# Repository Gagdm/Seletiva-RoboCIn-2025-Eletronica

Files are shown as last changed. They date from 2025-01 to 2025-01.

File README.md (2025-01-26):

# Conversor DC-DC com SIC437A

Este projeto implementa um conversor buck baseado no controlador SIC437A da Vishay.

## Objetivo
Desenvolver um regulador DC-DC, utilizando a ferramenta Altium Designer, que receba uma tensão de entrada entre 7,4V e 25,2V e forneça uma saída constante de 5V com corrente mínima de 5A. Além disso, é necessário atentar não apenas para a eficiência do circuito (mínima de 90%), mas também para o valor e as dimensões dos componentes.

---

Echematic

---

### 🟡
- Esta seção é responsável por receber a alimentação do circuito, filtrá-la e garantir uma entrada limpa e estável para o regulador de tensão.

#### Componentes
- JIN? : Um conector para a entrada de alimentação.
- CINB? (150uF): Capacitor de desacoplamento o qual remove ruídos transitórios, como picos de tensão causados pela fonte ou pelo chaveamento do regulador.
- CIND? (0,1uF): Também um capacitor de desacoplamento, trabalhando em conjunto com CINB? para aumentar a eficiência do filtro, abordando diferentes faixas de frequências indesejadas.
> No geral, Esses capacitores garantem que a tensão entregue ao regulador seja o mais estável possível, evitando ruídos que possam interferir no funcionamento do circuito.

---

### 🔴
- Formam um divisor de tensão que define a tensão de saída (VOUT) do regulador e alimentam o pino de feedback (FB), permitindo ao controlador ajustar o ciclo de trabalho (duty cycle) para manter a saída estável.

#### Componentes
- Os resistores RFB1 (73,2kΩ) e RFB2 (10kΩ) dividem a tensão de saída (VOUT) para gerar um sinal proporcional que é enviado ao pino FB do regulador. Dessa forma, ajustam a tensão de saída do regulador e garantem que o feedback forneça um sinal preciso ao controlador.

$$
RFB1 = \frac{FRB2 (V_{out} - V_{FB})}{V_{FB}}
$$

Temos, Vout = 5V, RFB1 = 10kΩ e Vfb = 0,6V (RFB1 e Vfb são definidos no datasheet do SIC437). Portanto,

$$
RFB1 = \frac{10.10^{3} (5 - 0,6)}{0,6} \simeq 73.333Ω \simeq 73,2kΩ
$$

- COUTD (0,1uF): Reduz ruídos de alta frequência na saída do regulador, ajudando a garantir uma tensão limpa e estável.
> Resumidamente, Permitem que o regulador monitore e ajuste a tensão de saída para mantê-la estável, além de determinam a tensão de saída por meio do divisor resistivo.

---

### 🟢
- Divisor de Tensão, esses resistores formam um divisor de tensão entre VIN (tensão de entrada) e o pino EN do regulador. O objetivo é garantir que o regulador seja habilitado somente quando a tensão de entrada atinge um valor mínimo seguro, prevenindo operação em condições inadequadas.

#### Componentes
- RenH (562kΩ)
- RenL (309kΩ)
> De forma geral, Funcionam como um divisor de tensão e proteção contra subvoltagem.

---

### 🔵 
- Esta parte auxilia o circuito de chaveamento do regulador, especialmente para operar o MOSFET superior em um regulador buck.

#### Componentes
- CBOOT? (0,1µF): Capacitor de bootstrap,fornecendo a energia necessária para acionar o MOSFET superior (high-side) durante o chaveamento, além de ser carregado toda vez que o MOSFET inferior (low-side) está conduzindo.
- RBOOT? (2Ω): Resistor em série com o capacitor de bootstrap, limitando a corrente para evitar danos ao capacitor ou ao circuito do regulador.
> O capacitor de bootstrap carrega uma tensão suficiente para abrir o MOSFET superior. Sem ele, o regulador não conseguiria operar eficientemente em topologias buck.

---

### 🟣
- Conecta a carga ao circuito regulador e fornece a energia estabilizada.

#### Componentes
- JOUT?: Conector de saída para o dispositivo ou circuito que será alimentado.
- Indutor (2,2µH): Componente fundamental em circuitos buck, uma vez que armazena energia durante o ciclo de chaveamento e libera energia para a carga durante o período off do MOSFET superior. Além disso, auxilia os capacitores a suaviza a corrente de saída.
- COUTA, COUTB, COUTC (47uF): Conjunto de capacitores eletrolíticos que estabilizam a tensão de saída e reduzem o ripple (ondulação), de forma conjunta com o indutor.
> O indutor trabalha em conjunto com os capacitores para garantir uma corrente constante para a carga, eliminando ondulações excessivas.

---

### 🟠
- Este é o coração do circuito, onde ocorre a conversão DC-DC do tipo buck. O regulador reduz a tensão de entrada para um valor de saída menor, controlando o fluxo de energia por meio de chaveamento.

#### Componentes
- IC Regulador Buck SIC437: Realiza a conversão de tensão utilizando MOSFETs internos que alternam entre condução e corte em alta frequência.

---

### 🟤
- Fornece suporte à tensão de VDRVVDRV, que alimenta os drivers internos dos MOSFETs do conversor.

#### Componentes
- CVDRV (4,7uF): É o capacitor conectado ao pino VDRV, que fornece energia aos drivers internos para alternar os MOSFETs. Os drivers alternam rapidamente em cada ciclo (frequência de comutação) e consomem corrente pulsante proporcional à carga de porta total dos MOSFETs.

---

### ⚫
- Trabalham juntos para garantir o funcionamento estável, seguro e configurável do regulador DC-DC.

#### Componentes
- CVDD (1uF): Estabilizar e filtrar a alimentação interna do regulador, reduzindo ruídos e garantindo o funcionamento correto do circuito interno, atuando como uma fonte de energia local para suavizar variações instantâneas de corrente demandadas pelos circuitos internos (como drivers de gate e lógica de controle).
> Reduz flutuações e ruídos na alimentação interna do IC regulador, além de ajuda a manter o regulador estável em operações de alta frequência.
- RM1 (100kΩ) e RM2 (499kΩ): Ajustar e configurar parâmetros relacionados ao funcionamento do regulador, como a corrente de operação ou outras características internas do IC. Esses resistores determinam o modo de operação do regulador, como o modo PWM (Pulse Width Modulation) ou modo PFM (Pulse Frequency Modulation), ou definem outros comportamentos específicos.
> Em resumo, Configuram o comportamento do regulador por meio de ajustes de tensão ou corrente e definem modos de operação ou parâmetros como frequência de chaveamento ou eficiência.
- RPG (100kΩ): Força um pino do regulador para o nível lógico baixo quando não há sinal ativo, garantindo comportamento definido e evitando flutuações indesejadas. Logo, Garante um estado definido (baixo) no pino de controle para evitar flutuações ou ativação acidental, devido a isso, Melhora-se a confiabilidade do circuito ao prevenir estados indesejados.
> Resumidamente, CVDD fornece suporte interno ao regulador, estabilizando sua alimentação, RM1 e RM2 ajustam o comportamento do regulador, permitindo personalização de parâmetros operacionais e RPG garante que o regulador tenha um comportamento previsível em estados inativos ou de inicialização.

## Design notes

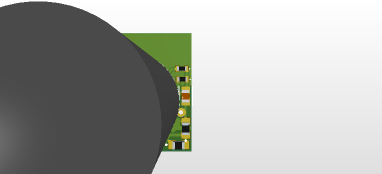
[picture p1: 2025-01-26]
PNG images of 3D view board/Details_TOP.png

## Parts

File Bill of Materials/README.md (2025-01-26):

# Link da planilha criada em baixo da tabela

Exportei como .pdf, pois os outros tipos estavam distorcendo os gráficos e/ou a tabela.
> Permiti a visualização de qualquer pessoa com link 😄.

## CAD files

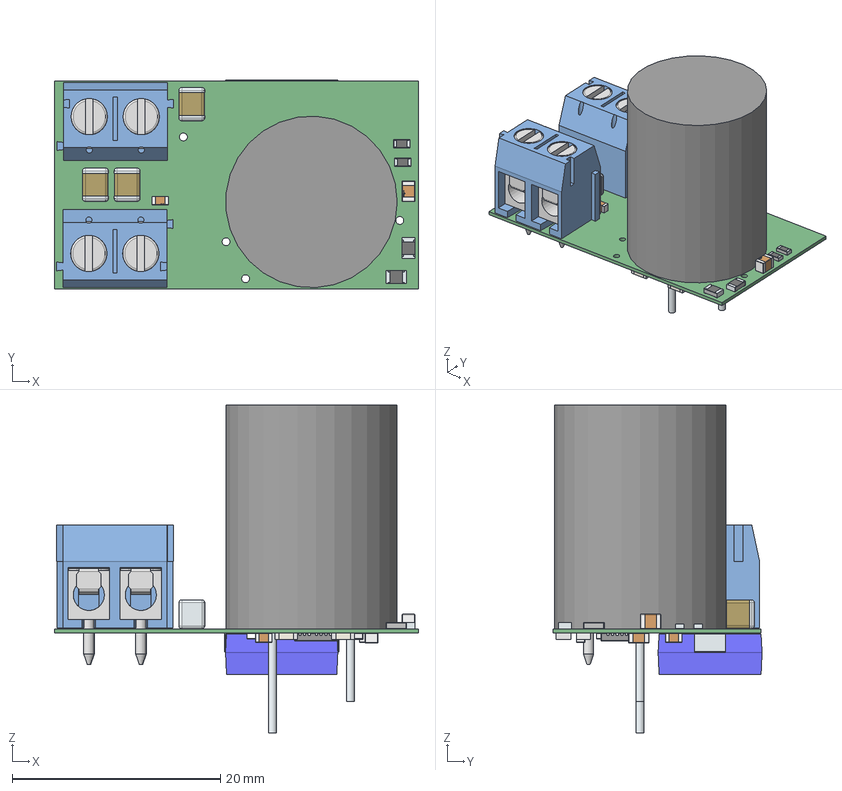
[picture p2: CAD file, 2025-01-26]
DC-DC_Buck_Converter.step
35.0 x 20.1 x 31.5 mm
6911027100xx_CAGE x 4
6911027100xx_PIN x 4
6911027100xx_VIS x 4
solidBody x 4
Terminal x 2
solidTop x 4
solidTerminal1 x 2
solidTerminal2 x 2
solidTerminal3 x 2
FilletPin1
FilletPin2
SimpleBody
Pin1
Pin2
Extruded x 6
Mid_Body
Mark
Res_Rohm_ESR03EZPJ101_eec x 5
side x 4
Murata x 2
Terminals x 2
AVX x 2
Pin
Taiyo Youde Logo 0.2mm

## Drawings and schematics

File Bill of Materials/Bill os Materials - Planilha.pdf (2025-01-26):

# Planilha de gastos - Seletiva Robôcin 2025

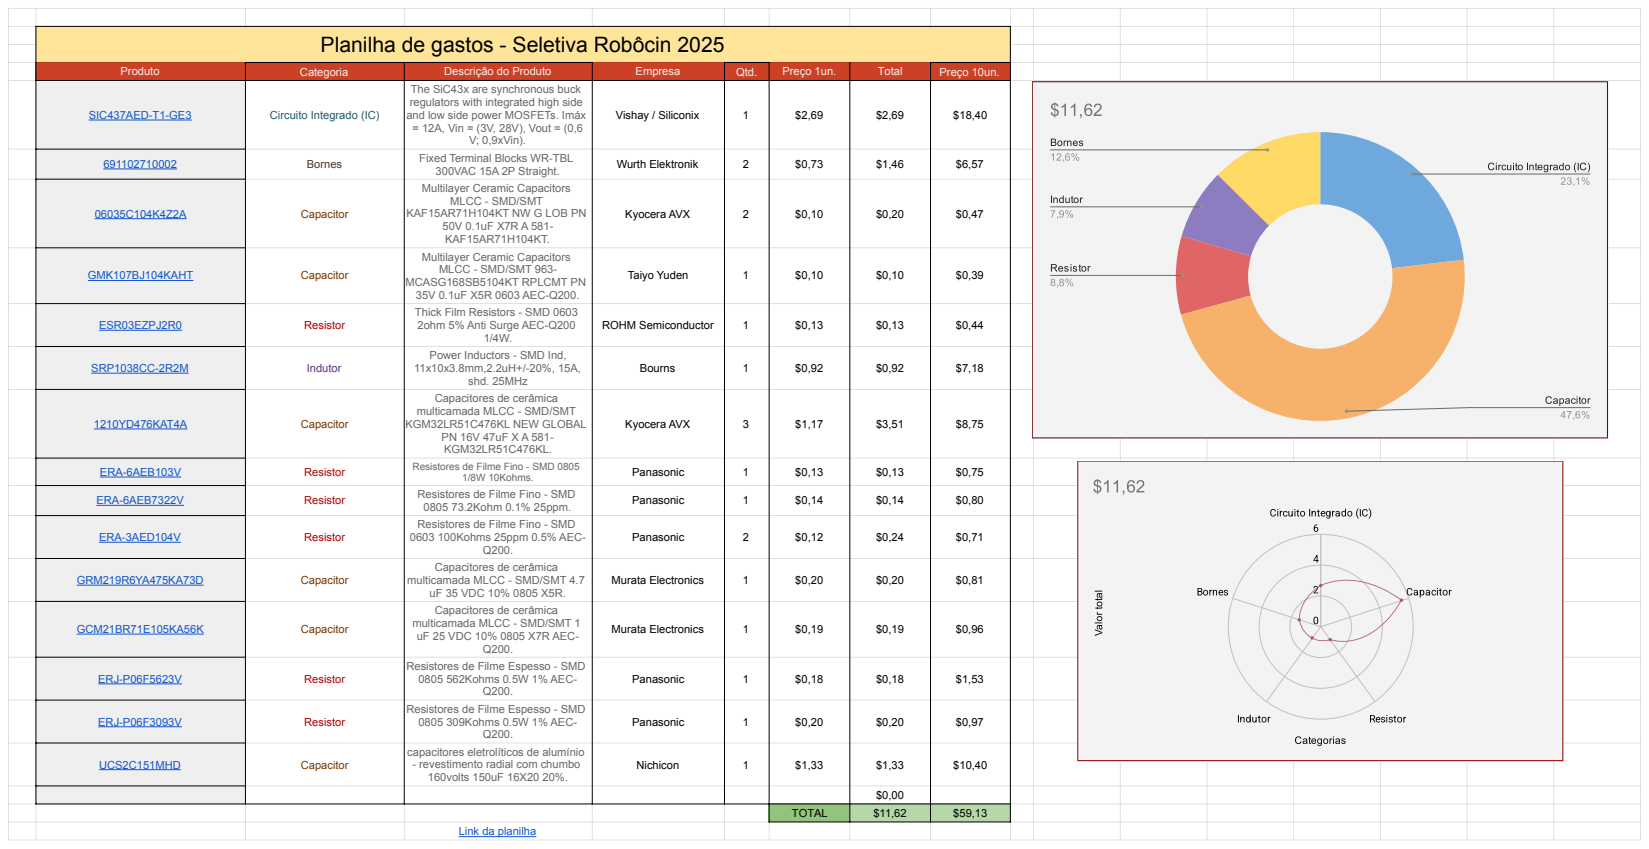
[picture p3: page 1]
Produto; Categoria; Descrição do Produto; Empresa; Qtd.; Preço 1un.; Total; Preço 10un.; SIC437AED-T1-GE3; Circuito Integrado (IC); V; 0,9xVin).; Vishay / Siliconix; Bornes; Fixed Terminal Blocks WR-TBL; 300VAC 15A 2P Straight.; Wurth Elektronik; Capacitor; 50V 0.1uF X7R A 581- KAF15AR71H104KT.; Kyocera AVX; GMK107BJ104KAHT; Taiyo Yuden; ESR03EZPJ2R0; Resistor; ROHM Semiconductor; SRP1038CC-2R2M; Indutor; shd. 25MHz; Bourns; 1210YD476KAT4A; ERA-6AEB103V; Resistores de Filme Fino - SMD 0805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

The SiC43x are synchronous buck
regulators with integrated high side
and low side power MOSFETs. Imáx
= 12A, Vin = (3V, 28V), Vout = (0,6

Multilayer Ceramic Capacitors MLCC - SMD/SMT KAF15AR71H104KT NW G LOB PN

Multilayer Ceramic Capacitors MLCC - SMD/SMT 963- MCASG168SB5104KT RPLCMT PN

35V 0.1uF X5R 0603 AEC-Q200.
Thick Film Resistors - SMD 0603
2ohm 5% Anti Surge AEC-Q200

Power Inductors - SMD Ind,

Capacitores de cerâmica multicamada MLCC - SMD/SMT KGM32LR51C476KL NEW GLOBAL PN 16V 47uF X A 581- KGM32LR51C476KL.

Resistores de Filme Fino - SMD
0603 100Kohms 25ppm 0.5% AEC- Q200.

Capacitores de cerâmica multicamada MLCC - SMD/SMT 4.7

uF 35 VDC 10% 0805 X5R.
Capacitores de cerâmica multicamada MLCC - SMD/SMT 1

uF 25 VDC 10% 0805 X7R AEC- Q200.

Resistores de Filme Espesso - SMD
0805 562Kohms 0.5W 1% AEC- Q200.

0805 309Kohms 0.5W 1% AEC- Q200.

capacitores eletrolíticos de alumínio
- revestimento radial com chumbo
160volts 150uF 16X20 20%.

Link da planilha (https://docs.google.com/spreadsheets/d/1aYkIrsaS4RMnpr4kq7zhXJQIE2t0kX-dxmZHZJuou6I/edit?usp=sharing)

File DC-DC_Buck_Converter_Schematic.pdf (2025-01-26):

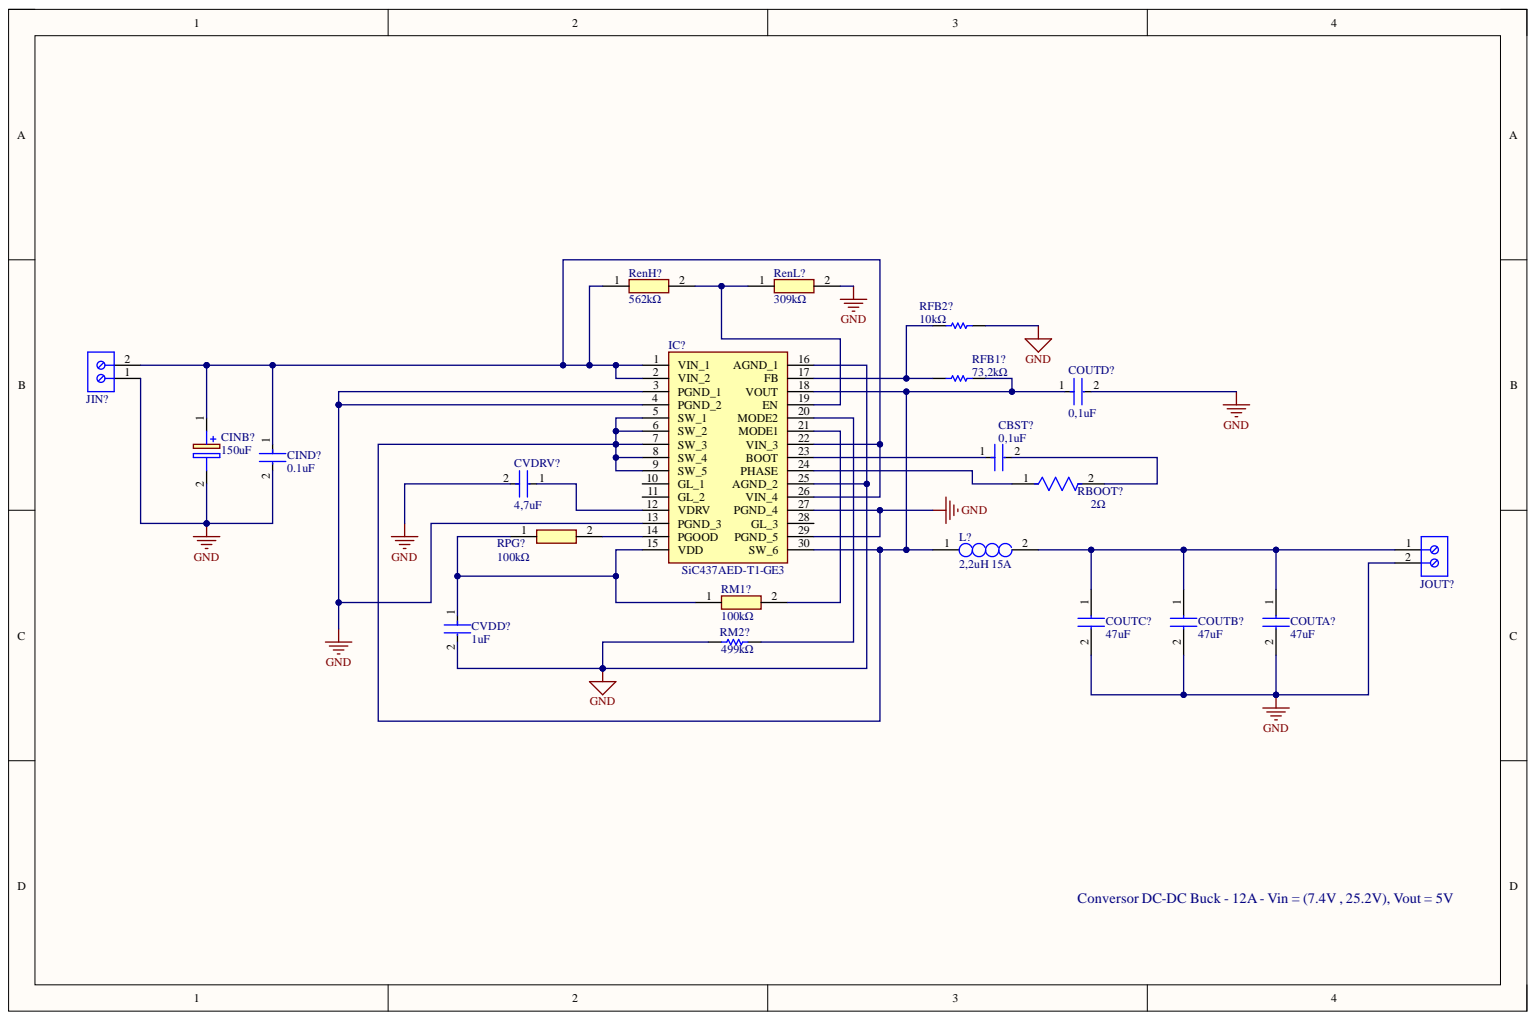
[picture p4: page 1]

4 | | 1 9
5 | VIN VIN SW | 2 0

ersor DC-DC Bu
